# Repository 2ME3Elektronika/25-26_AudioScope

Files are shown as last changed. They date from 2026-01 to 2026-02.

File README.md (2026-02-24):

# Idea of the project
A professional DIY project for real-time audio frequency spectrum visualization (20Hz-20KHz) using Raspberry Pi 4, Adafruit RGB Matrix HAT, and 64x64 RGB LED Matrix.



# Characteristics
- Visualizes frequencies from **20Hz-20kHz**.
- **Multiple** available imputs (Jack, RCA, ...).
- **Microphone** to test that the visualizer works.
- **Oled I2C display** with multiple functions.
# What is a **RGB matrix 64x64**
The **GRB Matrix 64x64** is an LED matrix display that allows images, animations, and text to be shown in a colorful and dynamic way. Its main features include:

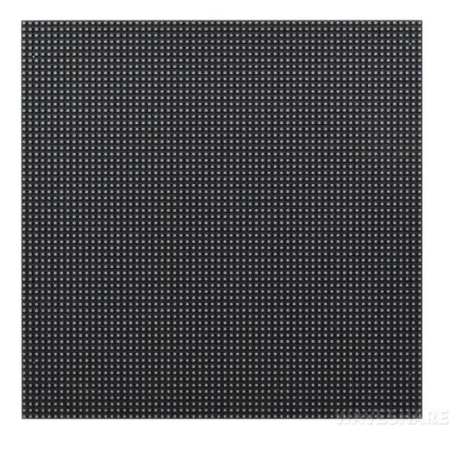
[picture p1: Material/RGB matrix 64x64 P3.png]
image alt

- **64x64 LED matrix:** Composed of 64 rows and 64 columns, totaling 4096 individual LEDs.
- **GRB color format:** Each LED is RGB (Red, Green, Blue), but the color data is sent in Green → Red → Blue order, ensuring colors display correctly.
- **Microcontroller control:** Can be driven with boards like Arduino or Raspberry Pi using specific matrix drivers such as Hub75.
- **High display capability:** Suitable for showing graphics, animations, and text in real time.
- **Standard protocol compatibility:** Allows efficient color data transfer and matrix synchronization.

In this project, the GRB Matrix 64x64 is responsible for displaying a **frequency** into a animated **FFT**, working together with the microcontroller that manages the system logic.

# Hardware 
Here’s a link to the guide for all the hardware you’ll need for this project

(https://github.com/2ME3Elektronika/25-26_AudioScope/blob/5edb63df820f065019aefbd5968ed1fb7cb71b74/HARDWARE.md)

# How To Use It?
1. Conect the power supply cable to a plug.
2. Click the power on **Button**.
3. Select the option you want to use with the **Rotary Encoder**.

Depending of the option you choose there are two routes.

## Microphone test mode
If you chose the **Microphone Test Mode**:

4. Talk to the microphone.
5. See if the display is showing the voice frequencies into FFT.

## Amplifier Test Mode
If you chose the **Amplifier Test Mode**:

4. Insert the output of the amplifier into of the inputs of the AudioScope.
5. See if the display is showing the frequencies into FFT.

# Preview Of The Project

Gemini_Generated_Image_q8y5mxq8y5mxq8y5
.
c96424af-a062-4ec9-849e-a771dd6d81b2aaaaa

## How the System Processes Audio
To turn raw sound into those dancing bars on your 64x64 matrix, the Raspberry Pi performs several complex operations in milliseconds.

### The Digital Processing Chain
1.  **Sampling:** The Pi captures the analog signal (Jack/RCA/Mic) via a USB Sound Card or I2S ADC at a standard rate (usually 44.1kHz).
2.  **FFT Algorithm:** The system applies a **Fast Fourier Transform**. This mathematical process takes the "messy" time-domain wave and breaks it into its constituent frequencies.
3.  **Mapping:** Since the matrix has 64 columns, the $20\text{Hz} - 20\text{kHz}$ range is divided into 64 discrete "bins":
    * **Lower bins (left):** Kick drums and bass guitar.
    * **Higher bins (right):** Cymbals and hi-hats.
4.  **Rendering:** The Adafruit RGB Matrix HAT translates these values into PWM (Pulse Width Modulation) signals to drive the HUB75 interface.

---

## Software Architecture
The system uses a high-performance stack to ensure real-time response without lag:

| Component | Function |
| :--- | :--- |
| **Python / C++** | Main logic & Rotary Encoder interrupt handling. |
| **ALSA / PortAudio** | Linux audio interface to "listen" to the input stream. |
| **rpi-rgb-led-matrix** | Low-level C++ driver for high-speed LED flickering. |
| **Luma.OLED** | Library for the I2C menu system and status display. |

---

## Expected Visual Modes
Customize your experience by switching between these visualization styles:

* **Classic Bar Spectrum:** Vertical bars with "peak drop" (a single pixel that stays at the top before falling).
* **Spectrogram:** A "waterfall" view where frequencies scroll downward over time.
* **Mirror Mode:** Bars grow from the horizontal center both upward and downward.
* **Pulse Mode:** The entire matrix pulses in color based on the intensity of the sub-bass.

---

## Final Tips for Success
> [!IMPORTANT]
> **Power Supply:** A 64x64 matrix can pull up to 4A. Use a **5V 10A** power supply to ensure stability for both the Pi and the LEDs.

* **Noise Floor:** Implement a software **noise gate** to keep the display clean when no music is playing.
* **Performance:** Use **Raspberry Pi OS Lite** to minimize background tasks and prevent "flickering" on the matrix.

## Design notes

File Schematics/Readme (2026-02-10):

You can download a Proteus file that lets you view the electrical circuit and create or order the PCB.

Each of the components are named in order to represent what they are inside of the pcb.

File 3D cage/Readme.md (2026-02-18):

# Building information

This section has been created to include the 3D part designs of the project. Throughout the development process, the project has evolved significantly over time, which has led to multiple changes and improvements in the designs. The files presented here correspond to the final versions of the parts.

Additionally, I have attached some images showing the initial design concepts to illustrate how the project has progressed from its early ideas to the final result.

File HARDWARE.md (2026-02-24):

#  Hardware Requirements

### Core Components
  1. **Raspberry Pi 4 Model B** (2GB or 4GB RAM recommended)

  2. **Adafruit RGB Matrix HAT + RTC for Raspberry Pi**
     - Provides clean 5V power to LED matrix and level-shifted outputs

  4. **64x64 RGB LED Matrix Panel - 3mm Pitch**
      - 3mm pitch recommended for better resolution
  
  5. **5V 4A (4000mA) Power Supply**
      - For powering the LED matrix
      - Minimum 4A for full brightness on 64x64 matrix

### Audio Input Hardware

### For Low-Level Signals (10mV-1V)
 **ADS1115 16-Bit ADC**
   - 4-channel, 16-bit resolution
   - I2C interface
   - Programmable gain amplifier (PGA)
   - Adafruit Product ID: 1085 or compatible

 **Input Protection Circuit Components:**
   - 1x Voltage divider resistors (10kΩ and 1kΩ)
   - 1x Capacitor 10µF (DC blocking)
   - 1x Op-amp (optional): TL072 or similar for signal conditioning
   - 2x Zener diodes 3.3V (input protection)
   - BNC or 3.5mm jack connector

### For High-Power Audio (40W Output)
#### USB Audio Interface
   - Any USB audio interface compatible with Raspberry Pi
   - Recommended: Behringer UCA202 or similar
   - Line-level input capability

** Voltage Divider/Attenuator Circuit:**
   - Resistors: 100kΩ and 10kΩ (10:1 attenuation)
   - Capacitor: 100µF (power supply decoupling)
   - Heat-shrink tubing or enclosure
   - Speaker wire connectors
     
#### Menu/Display Components
**Character LCD 20x4 with I2C backpack** OR **128x64 OLED Display**
   - For menu system and settings display
   - I2C interface preferred for easy connection
   - Options:
     - HD44780-compatible 20x4 LCD (recommended)
     - SSD1306 128x64 OLED display

## Power Considerations

### Power Budget
- Raspberry Pi 4: ~3W (600mA @ 5V)
- RGB Matrix HAT: ~0.5W (100mA @ 5V)
- 64x64 LED Matrix (full white): ~20W (4000mA @ 5V)
- 64x64 LED Matrix (typical usage): ~10W (2000mA @ 5V)
- LCD Display: ~0.5W (100mA @ 5V)
- USB Audio Interface: ~0.5W (100mA @ 5V)

**Total:** ~15W typical, ~25W maximum

## Power Supply Recommendations
- Use separate 5V 4A supply for LED matrix (via RGB Matrix HAT)
- Raspberry Pi can be powered from HAT's barrel jack
- Or use official Raspberry Pi 15W USB-C power supply
  
## Safety Notes
- Never exceed voltage ratings
- Use fuses on all power inputs
- Ensure proper grounding
- Keep high-power audio circuit isolated
- Use insulated connectors and enclosures

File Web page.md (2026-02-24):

---

## 🖥️ Web Interface
To interact with the project data and monitoring system, we have developed a dedicated web dashboard. You can access the live interface by clicking the banner below:

Web Preview (https://147810376.hs-sites-eu1.com/home)

*Click on the image to open the live dashboard and explore the AudioScope controls.*

### Key Web Features:
* **Real-time Monitoring:** Visual feedback of the audio signals processed by the Raspberry Pi.
* **Remote Control:** Adjust parameters and visualization modes directly from your browser.
* **Device Status:** Check the connectivity and system health of your AudioScope unit.

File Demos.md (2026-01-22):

To be able of running some demos we decided to use the next website
(https://learn.adafruit.com/adafruit-rgb-matrix-plus-real-time-clock-hat-for-raspberry-pi/install-manually)

To see if our 64x64 rgb led matrix the next library can be used to see some demos.
-     git clone https://github.com/hzeller/rpi-rgb-led-matrix.git  cd rpi-rgb-led-matrix  make

Once you´re inside of the examples-api-use subdirectory the next code can be used to prove some examples. By changing the number at the end of the code (0-9) different samples can be put on the 64x64 matrix
-     sudo ./demo -D 0

If you encounter an image problem when running the demo, you should open the demo.py file located in the examples-api-use subdirectory and find the two lines that say rows and columns and change them from 32 to 64.

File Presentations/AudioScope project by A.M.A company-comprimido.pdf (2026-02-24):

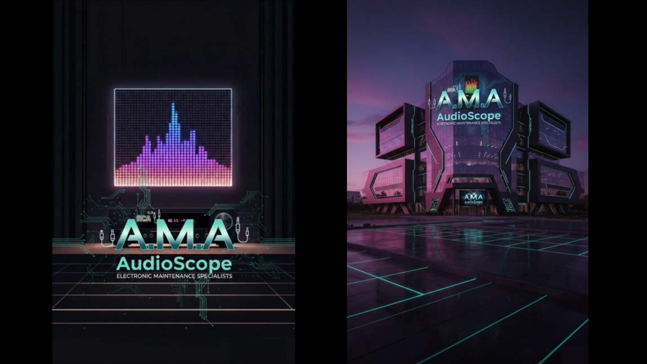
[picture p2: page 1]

# WHO ARE WE?

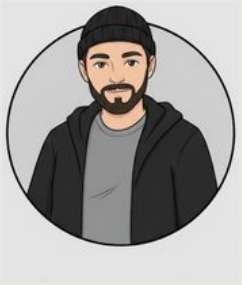
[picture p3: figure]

## Programer and CEO of the company

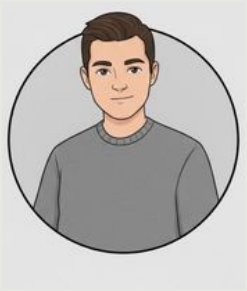
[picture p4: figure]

## 3D designer, assembler and marketing manager

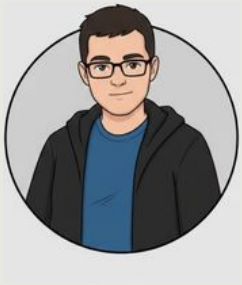
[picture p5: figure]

## PCB designer/soldier and troubleshooting

# WHAT IS OUR PURPOSE?

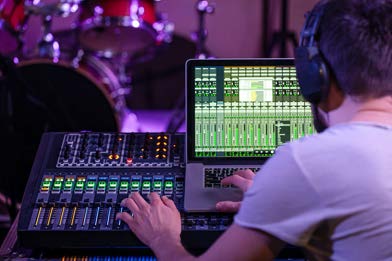
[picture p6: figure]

- Audio System
Optimization

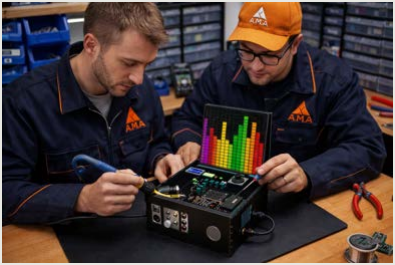
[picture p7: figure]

- Preventive Maintenance
- Hardware Restoration
- Component-level Repair

# WHAT IS AUDIOSCOPE?

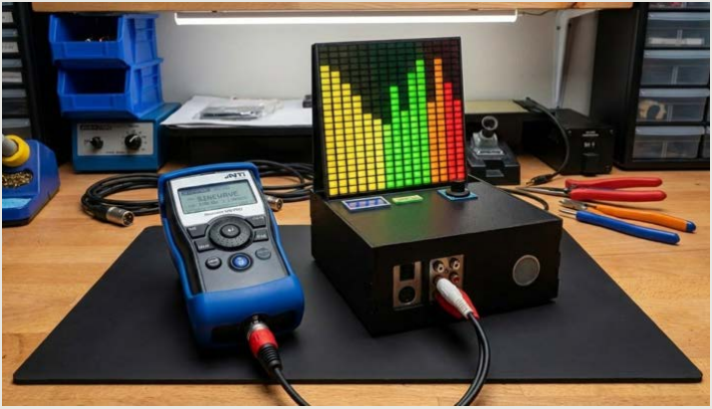
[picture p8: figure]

Video (https://drive.google.com/drive/folders/1TKRi724KOL6Fbhr36j2Ks8M4P-jSvRjH?usp=sharing)

# WHAT IS AUDIOSCOPE PRODUCT FOCUSED ON?

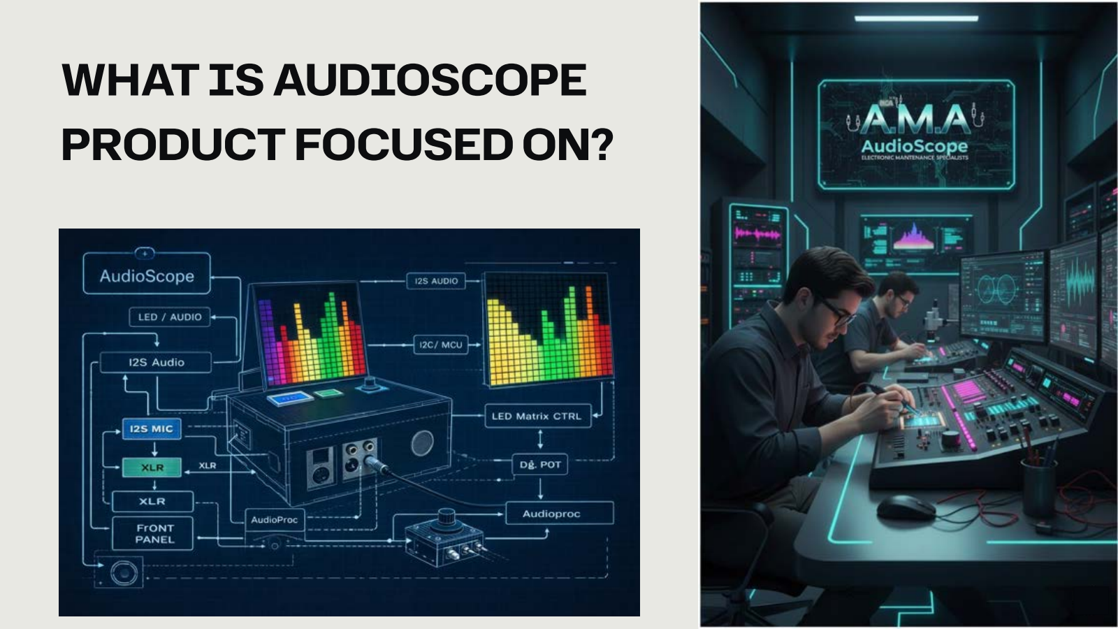
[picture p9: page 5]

# THE ROLE OF AI IN AUDIOSCOPE

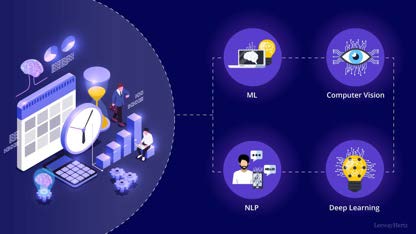
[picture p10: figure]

- Expert guidance in choosing the most compatible and high-performance electronic elements for the project.

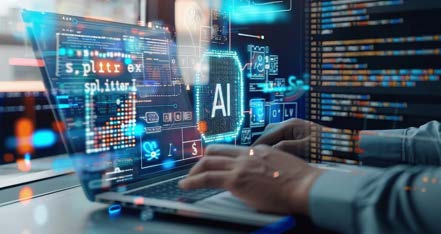
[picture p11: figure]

- Using AI suggestions to optimize code logic and ensure the fastest possible frequency processing.

# FUTURE IMPROVEMENTS TO AUDIOSCOPE

- Connectivity:
Integration of Bluetooth
and Wi-Fi streaming for
a wireless experience.
- Smart Features: AI-driven genre recognition to
automatically adapt visual styles.

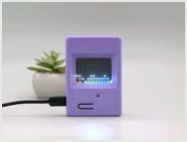
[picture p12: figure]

- Audio Quality: Upgrading to high-end I2S DACs for
professional-grade signal
processing.
- Portability: Implementation of internal battery systems and compact housing.

# DRIVING TOMORROW'S SUCCESS, TODAY

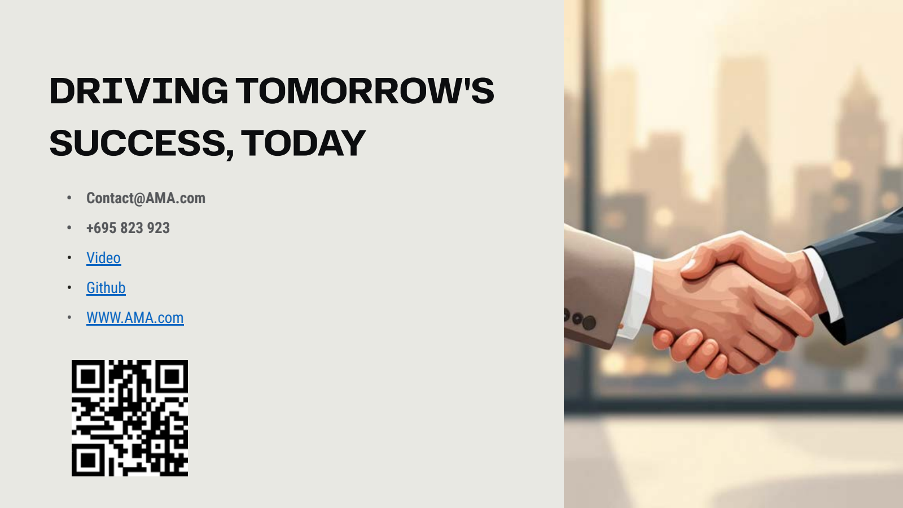
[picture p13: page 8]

- Contact@AMA.com
- +695 823 923
- Video (https://drive.google.com/drive/folders/1TKRi724KOL6Fbhr36j2Ks8M4P-jSvRjH?usp=sharing)
- Github (https://github.com/2ME3Elektronika/25-26_AudioScope)
- WWW.AMA.com (https://147810376.hs-sites-eu1.com/home)

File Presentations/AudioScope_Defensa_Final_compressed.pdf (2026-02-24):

# AUDIOSCOPE

## Sistema Embebido de Visualización Espectral en Tiempo Real

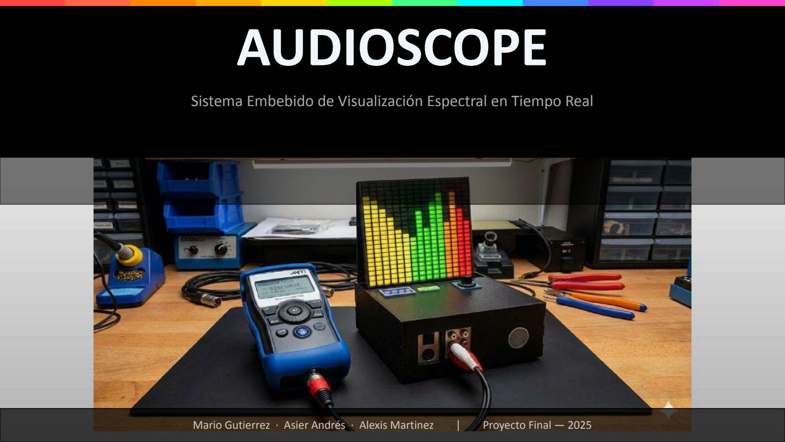
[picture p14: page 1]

Mario Gutierrez · Asier Andrés · Alexis Martinez | | | Proyecto Final — 2025

# AUDIOSCOPE — VISIÓN GENERAL

### Analizador espectral embebido con visualización RGB 64×64 y control I²C

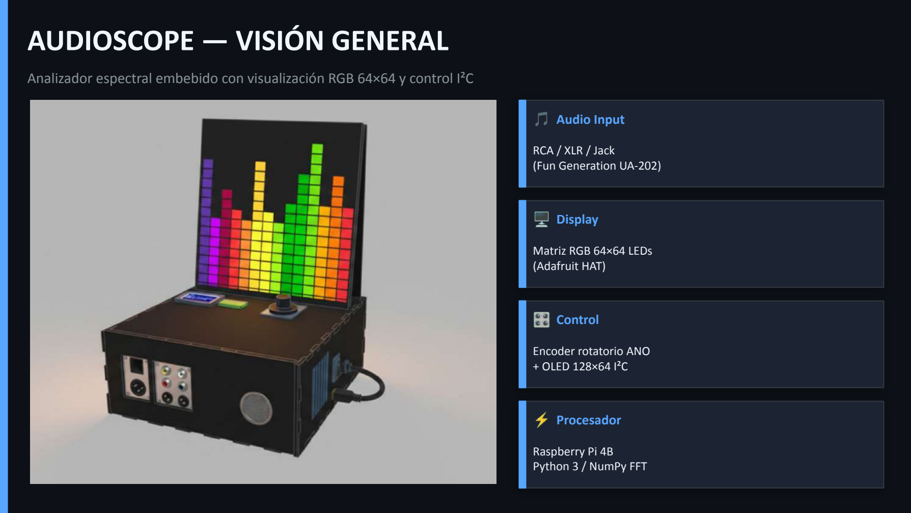
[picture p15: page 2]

🎵 Audio Input

RCA / XLR / Jack
(Fun Generation UA-202)

🖥 Display

Matriz RGB 64×64 LEDs
(Adafruit HAT)

🎛 Control

Encoder rotatorio ANO
+ OLED 128×64 I²C

⚡ Procesador

Raspberry Pi 4B
Python 3 / NumPy FFT

# 01 — ARQUITECTURA HARDWARE

### Diagrama de conexiones y flujo de señal completo

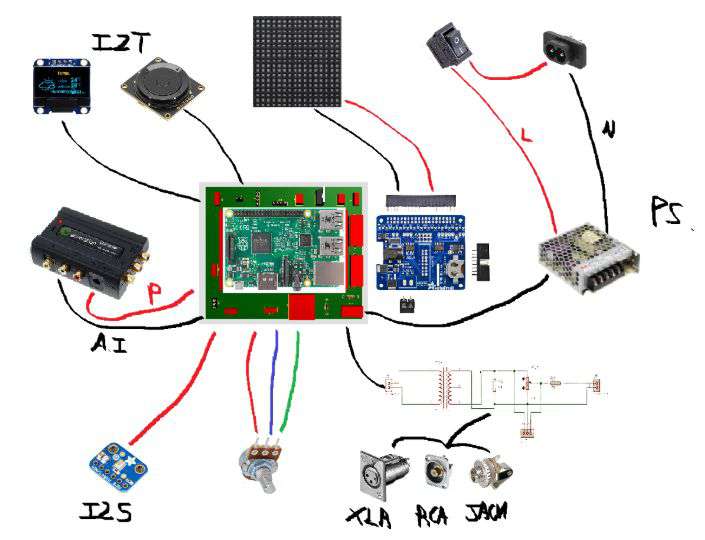
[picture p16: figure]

# 02 — PINOUT RASPBERRY PI & BUS I²C

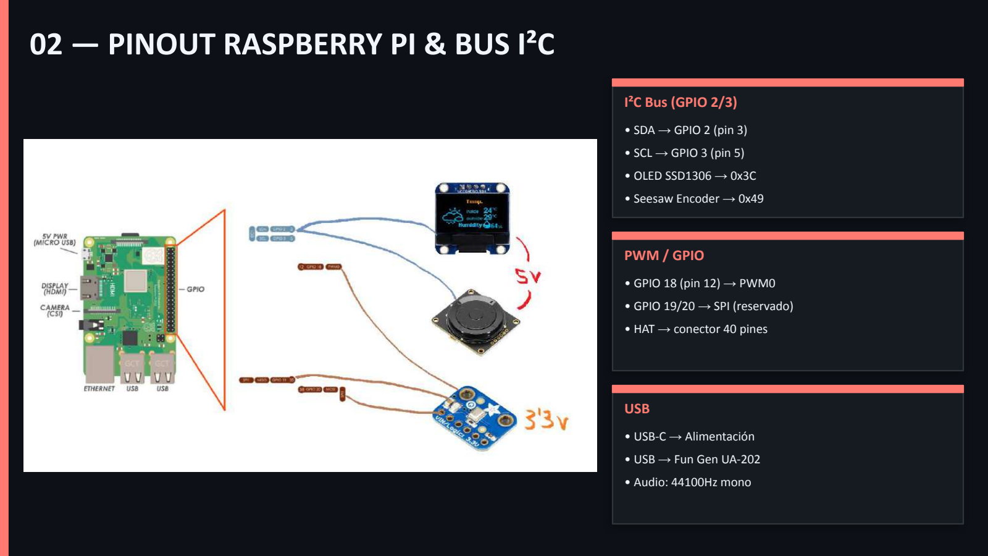
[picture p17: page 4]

I²C Bus (GPIO 2/3)

- SDA → GPIO 2 (pin 3)
- SCL → GPIO 3 (pin 5)
- OLED SSD1306 → 0x3C
- Seesaw Encoder → 0x49

PWM / GPIO

- GPIO 18 (pin 12) → PWM0
- GPIO 19/20 → SPI (reservado)
- HAT → conector 40 pines

USB

- USB-C → Alimentación
- USB → Fun Gen UA-202
- Audio: 44100Hz mono

# 03 — ARQUITECTURA SOFTWARE

### 3 módulos Python · threading.Thread · Callback de audio asíncrono

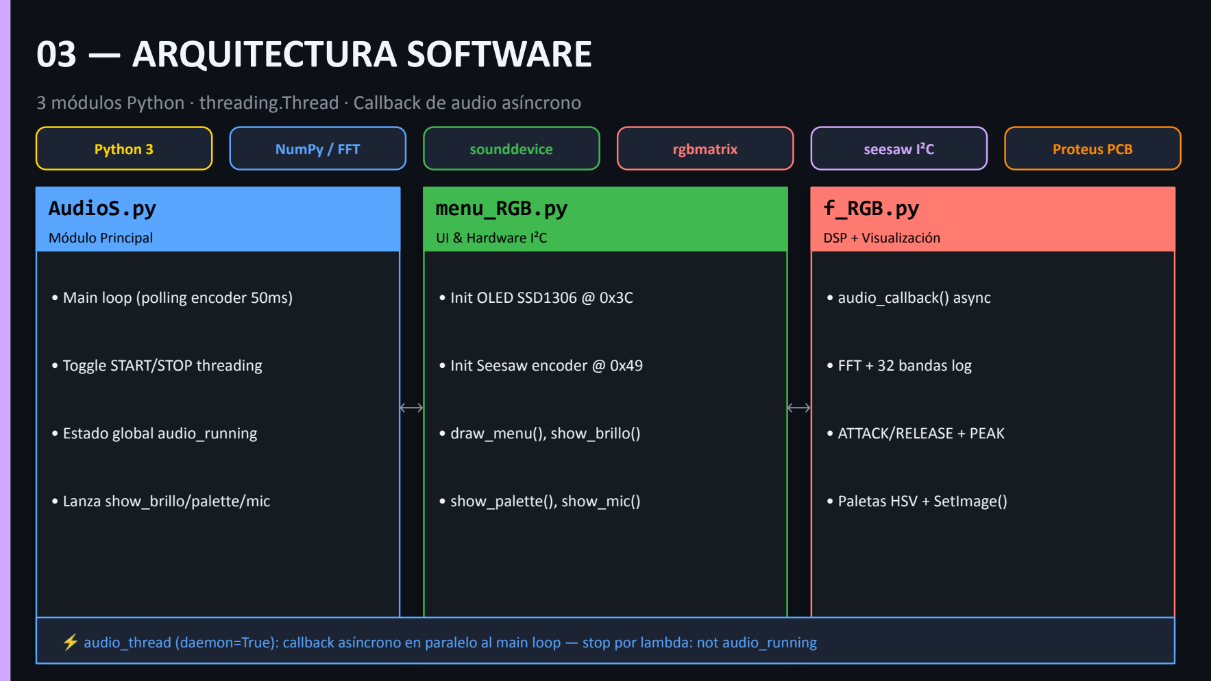
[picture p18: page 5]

Python 3 | NumPy / FFT | sounddevice | rgbmatrix | seesaw I²C | Proteus PCB

## AudioS.py

Módulo Principal

- Main loop (polling encoder 50ms)
- Toggle START/STOP threading
- Estado global audio_running
- Lanza show_brillo/palette/mic

## menu_RGB.py

UI & Hardware I²C

- Init OLED SSD1306 @ 0x3C
- Init Seesaw encoder @ 0x49
- draw_menu(), show_brillo()
- show_palette(), show_mic()

## f_RGB.py

DSP + Visualización

- audio_callback() async
- FFT + 32 bandas log
- ATTACK/RELEASE + PEAK
- Paletas HSV + SetImage()
⟷ | ⟷

audio_thread (daemon=True): callback asíncrono en paralelo al main loop — stop por lambda: not audio_running

# 04 — PIPELINE DE AUDIO & DSP

### Captura USB → Windowing → FFT → 32 bandas logarítmicas → Normalización

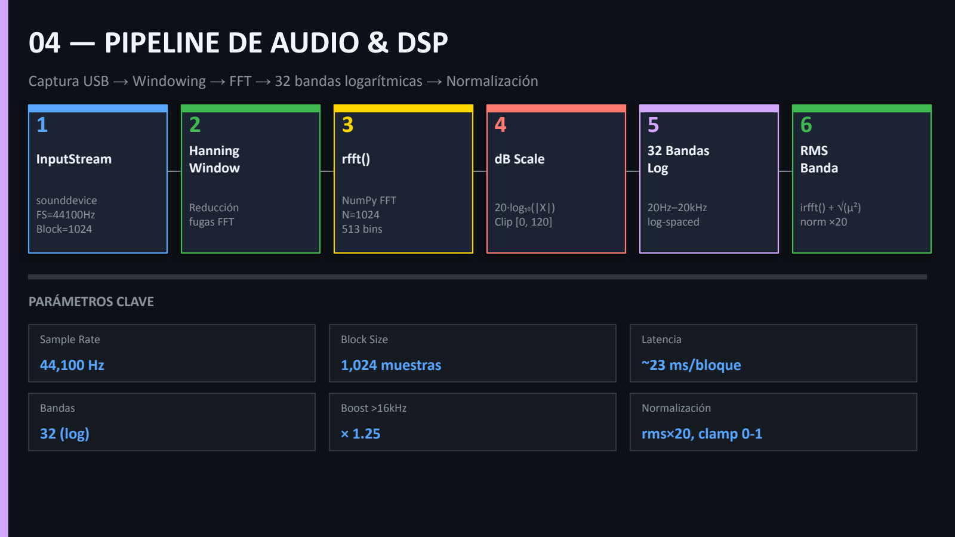
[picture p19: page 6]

1

InputStream

sounddevice
FS=44100Hz
Block=1024

→

2

Hanning
Window

Reducción
fugas FFT

→

3

rfft()

NumPy FFT
N=1024
513 bins

→

4

dB Scale

20·log₁₀(|X|)
Clip [0, 120]

→

5

### 32 Bandas

Log

20Hz–20kHz
log-spaced

→

6

RMS
Banda

irfft() + √(μ²)
norm ×20

PARÁMETROS CLAVE

Sample Rate
44,100 Hz

Block Size

### 1,024 muestras

Latencia

### ~23 ms/bloque

Bandas

### 32 (log)

Boost >16kHz
× 1.25

Normalización

### rms×20, clamp 0-1

# 05 — MOTOR DE VISUALIZACIÓN RGB

### Suavizado dinámico, barras de pico y 5 paletas HSV con degradado 3D

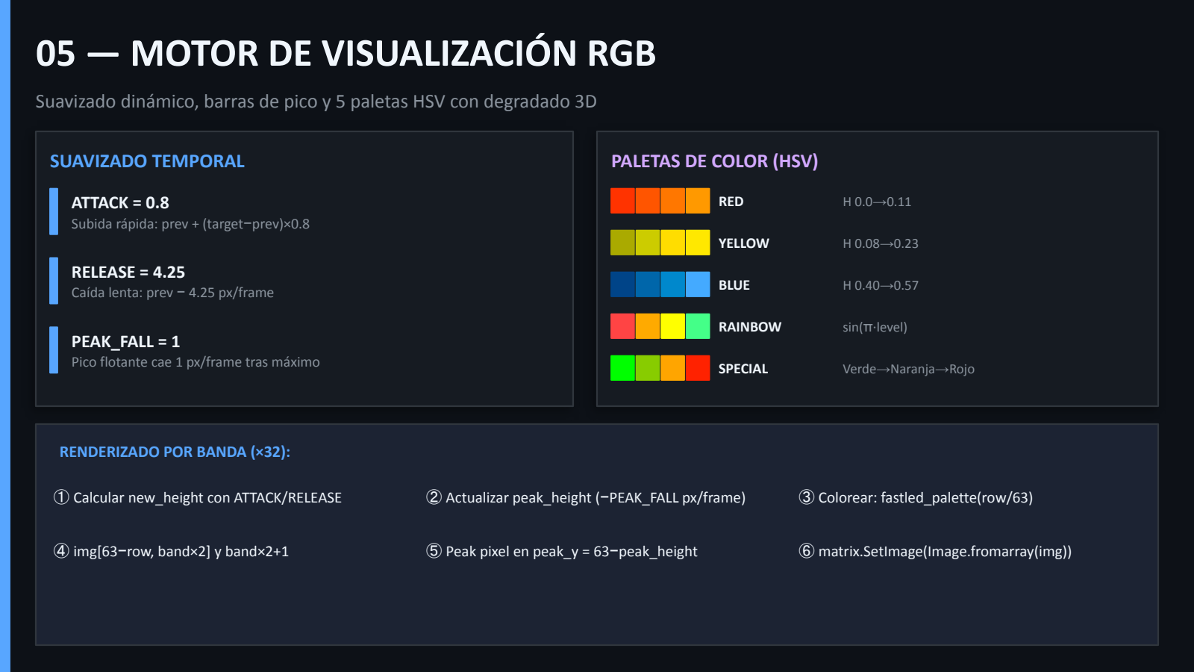
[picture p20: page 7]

### SUAVIZADO TEMPORAL

ATTACK = 0.8
Subida rápida: prev + (target−prev)×0.8

RELEASE = 4.25
Caída lenta: prev − 4.25 px/frame

PEAK_FALL = 1
Pico flotante cae 1 px/frame tras máximo

### PALETAS DE COLOR (HSV)

RED | H 0.0→0.11
YELLOW | H 0.08→0.23
BLUE | H 0.40→0.57
RAINBOW | sin(π·level)
SPECIAL | Verde→Naranja→Rojo

RENDERIZADO POR BANDA (×32):

① Calcular new_height con ATTACK/RELEASE | ② Actualizar peak_height (−PEAK_FALL px/frame) | ③ Colorear: fastled_palette(row/63)
④ img[63−row, band×2] y band×2+1 | ⑤ Peak pixel en peak_y = 63−peak_height | ⑥ matrix.SetImage(Image.fromarray(img))

# 06 — INTERFAZ DE USUARIO

### OLED 128×64 (0x3C) + Encoder ANO Seesaw I²C (0x49) + 4 botones

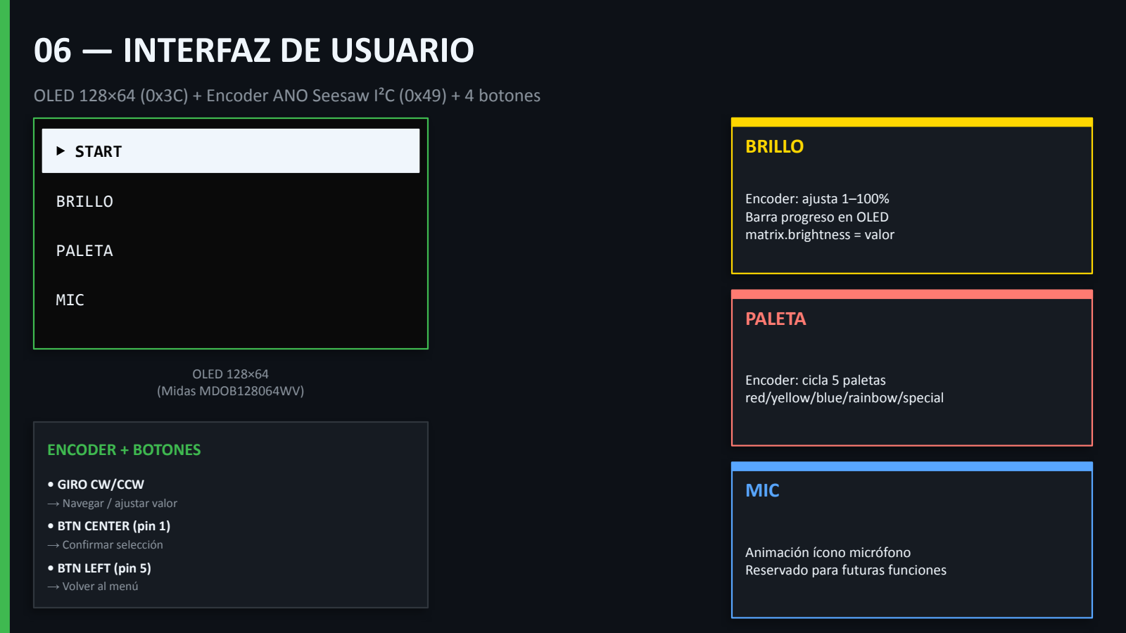
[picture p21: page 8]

- START

BRILLO

PALETA

MIC

OLED 128×64
(Midas MDOB128064WV)

ENCODER + BOTONES

- GIRO CW/CCW
→ Navegar / ajustar valor
- BTN CENTER (pin 1)
→ Confirmar selección
- BTN LEFT (pin 5)
→ Volver al menú

## BRILLO

Encoder: ajusta 1–100%
Barra progreso en OLED
matrix.brightness = valor

## PALETA

Encoder: cicla 5 paletas
red/yellow/blue/rainbow/special

## MIC

Animación ícono micrófono
Reservado para futuras funciones

# 07 — DISEÑO MECÁNICO & CARCASA

### Piezas diseñadas en Inkscape + MakerCase — Impresión 3D

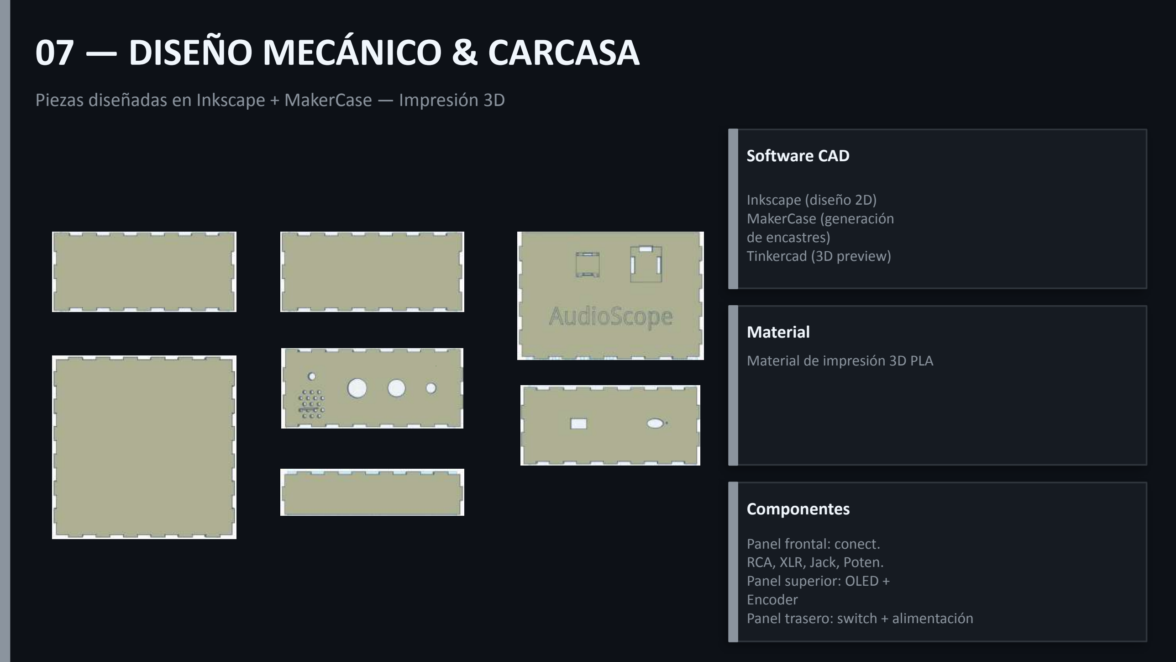
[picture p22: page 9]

Software CAD

Inkscape (diseño 2D)
MakerCase (generación
de encastres)
Tinkercad (3D preview)

Material

Material de impresión 3D PLA

Componentes

Panel frontal: conect.
RCA, XLR, Jack, Poten.
Panel superior: OLED +
Encoder
Panel trasero: switch + alimentación

# 08 — DISEÑO ELECTRÓNICO (Proteus + PCB)

### Esquemático en Proteus · PCB 3D con fuente de alimentación integrada

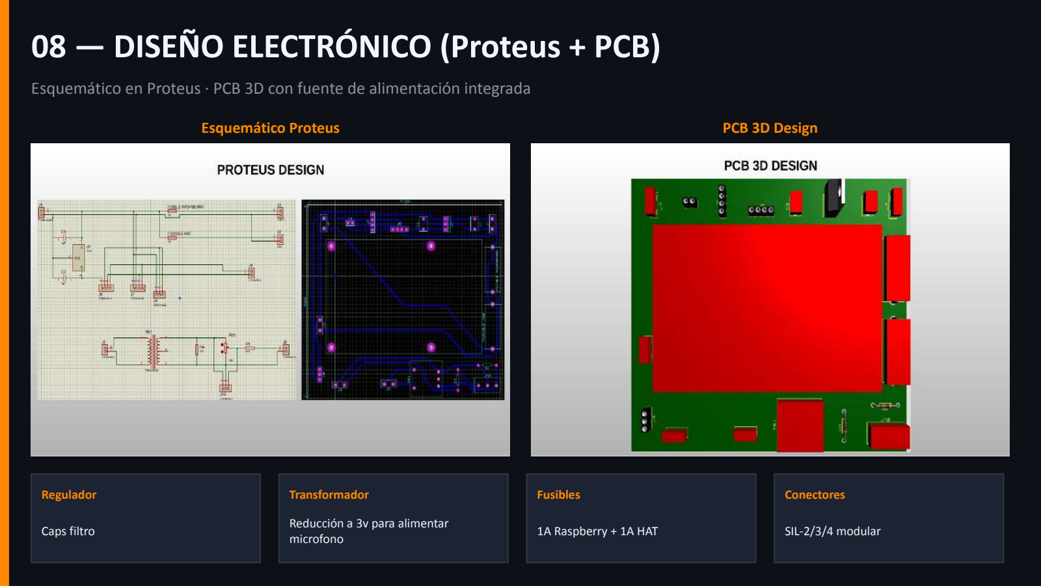
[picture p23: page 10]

Esquemático Proteus | PCB 3D Design

Regulador

Caps filtro

Transformador

Reducción a 3v para alimentar microfono

Fusibles

1A Raspberry + 1A HAT

Conectores

SIL-2/3/4 modular

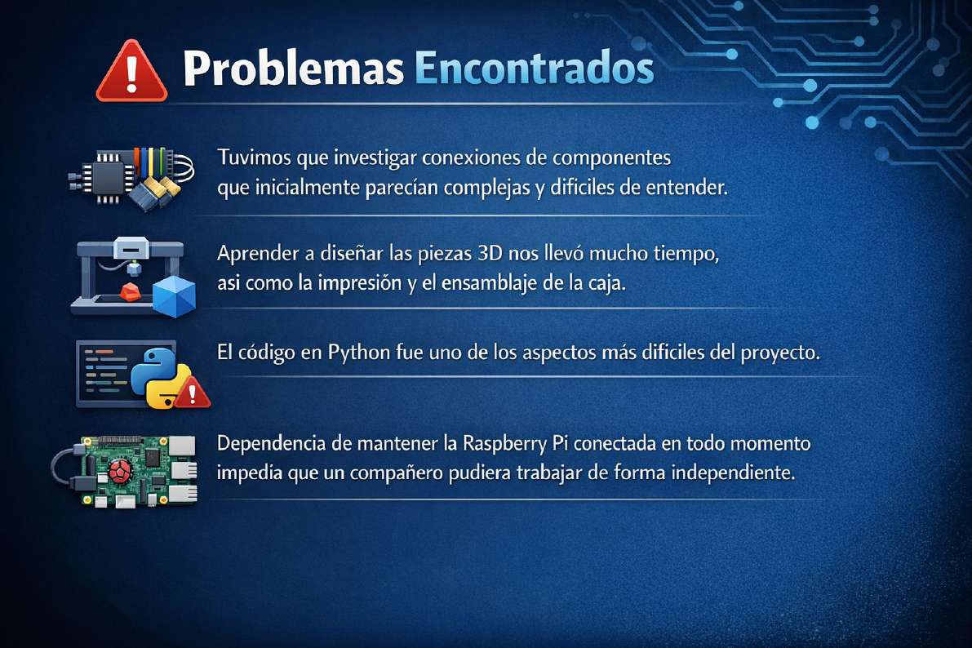
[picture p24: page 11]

# 🔧 FUTURAS MEJORAS

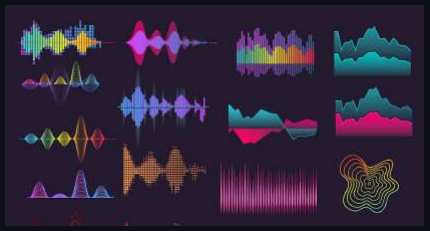
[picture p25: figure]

Más estilos visuales

Osciloscopio(sinusoidal), circular, etc…


Pantalla RGB mayor

Configurar una segunda matriz P3 64×64


Altavoces integrados

Escuchar el audio en el dispositivo a la vez que se pueda visualizar el display

# A.M.A

# AudioScope


Electronic Maintenance Specialists

- Video demo (https://drive.google.com/drive/folders/1TKRi724KOL6Fbhr36j2Ks8M4P-jSvRjH?usp=sharing)
⌥ | GitHub — código fuente (https://github.com/2ME3Elektronika/25-26_AudioScope)
| Webpage del proyecto (https://147810376.hs-sites-eu1.com/home)
| Instagram (https://www.instagram.com/audioscope2026/)
Escanea para
acceder al proyecto

Mario Gutierrez · Asier Andrés · Alexis Martinez

## TikTok (https://www.tiktok.com/@audioscope2026?is_from_webapp=1&sender_device=pc)

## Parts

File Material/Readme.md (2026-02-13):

# Oled I2C Display
We are using an I2C display to be able to visualize the different options available when using the AudioScope.

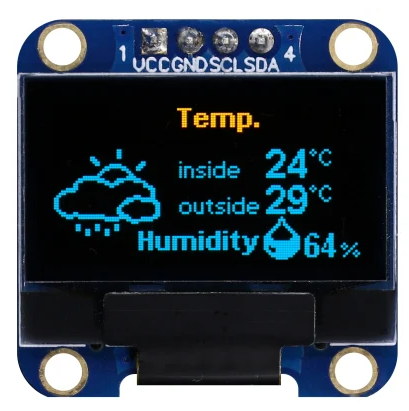
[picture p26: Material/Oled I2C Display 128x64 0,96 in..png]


## Connections
- **VCC:** It is supllied with 5v by the 5v 10A power supply.
- **GND:** It is conected to the GND of the power supply.
- **SDA (Serial Data):** it is connected to the pin SDA of the adafruit hat.
- **SCL (Serial Clock):** it is connected to the pin SCL of the adafruit hat.

# Oled I2C Rotatory Encoder
The rotatory encoder is used to select between the different options that the oled i2c display gives us.

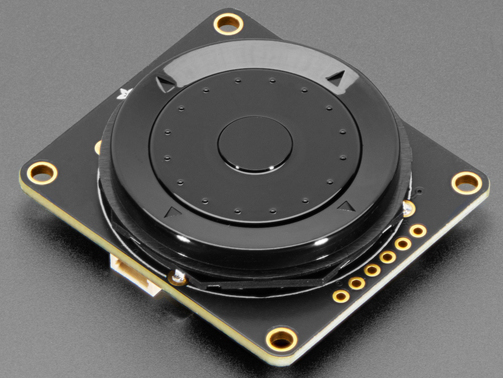
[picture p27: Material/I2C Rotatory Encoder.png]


## Connections
- **VCC:** It is supplied with 5v by the 5v 10A power supply.
- **GND:** It is conected to the GND of the power supply.
- **SDA (Serial Data):** it is connected to the pin SDA of the adafruit hat.
- **SCL (Serial Clock):** it is connected to the pin SCL of the adafruit hat.

# I2S Microphone
This microphone is used to be able to test that the AudioScope is working properly.

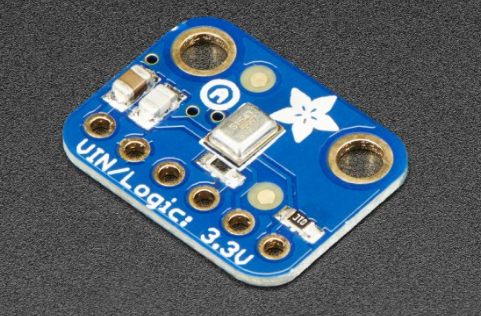
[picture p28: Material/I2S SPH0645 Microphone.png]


## Connections
- **VCC:** It is supplied with 3,3v that come out of the regulator.
- **GND:** It is conected to the GND of the power supply.
- **BCLK:** It is conected to the GPIO 18 of the adafruit hat
- **LRCL/WS:** It is conected to the GPIO 19 of the adafruit hat
- **DOUT/SD:** It is conected to the GPIO 20 of the adafruit hat
- **Optional L/R (Channel selection):** In order to have a secundary sound channel it is conected to the GND of the power suplly.

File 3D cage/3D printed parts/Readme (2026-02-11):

The following 3D models are specifically designed to be printed with a 3D printer. Each component has been optimized for additive manufacturing, considering printability, layer adhesion, and support requirements.

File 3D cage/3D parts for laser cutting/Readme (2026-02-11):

The following 3D models are specifically designed to be fabricated using laser cutting, not 3D printing. Although the components are presented in 3D format for easier visualization and assembly, each part is intended to be cut from flat materials (such as MDF, acrylic, or plywood) and then assembled.

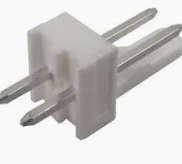
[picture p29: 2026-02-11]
Schematics/Material for PCB/Male 2 pin conector.png

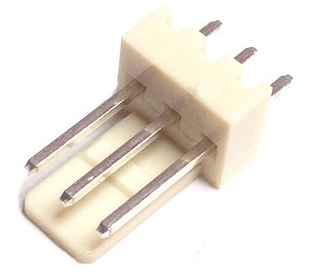
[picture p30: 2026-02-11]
Schematics/Material for PCB/Male 3 pin conector.png

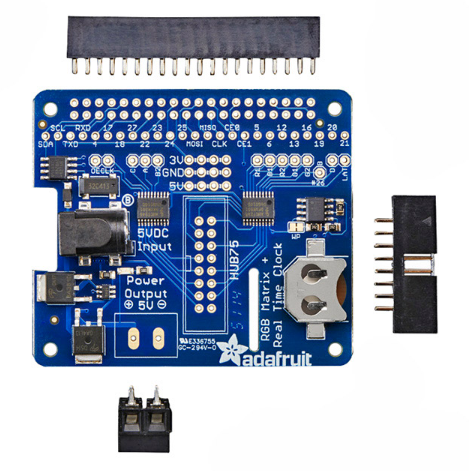
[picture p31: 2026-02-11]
Material/Adafruit RGB matrix hat.png

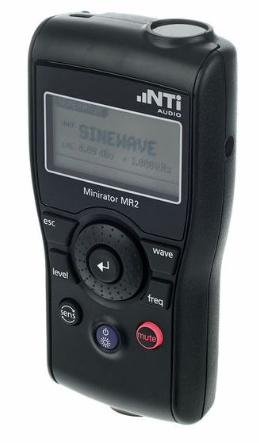
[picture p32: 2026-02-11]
Material/NTI Audio MR-2 Minirator.png

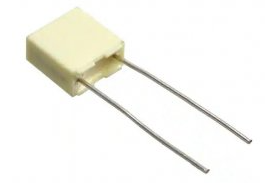
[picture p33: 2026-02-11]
Schematics/Material for PCB/1uf 63v capacitor.png

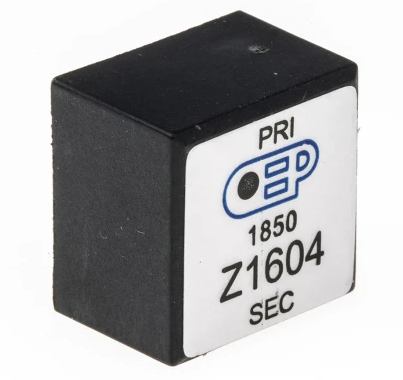
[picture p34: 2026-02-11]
Schematics/Material for PCB/Z1604 Transformer.png

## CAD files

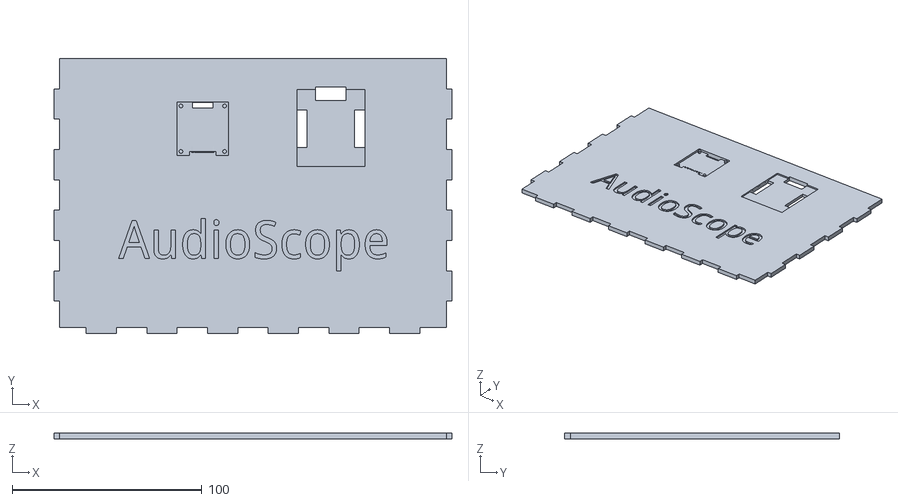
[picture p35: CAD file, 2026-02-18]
3D cage/3D printed parts/Pieza superior control AudioScope.stl
210.0 x 145.0 x 3.00

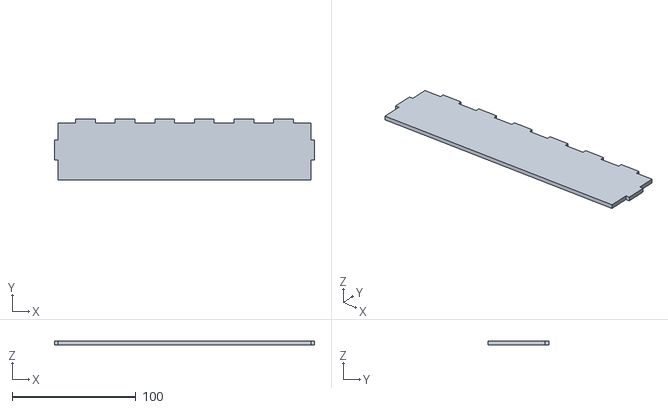
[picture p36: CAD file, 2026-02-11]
3D cage/3D printed parts/Pieza superior corta AudioScope.stl
210.0 x 49.0 x 3.00

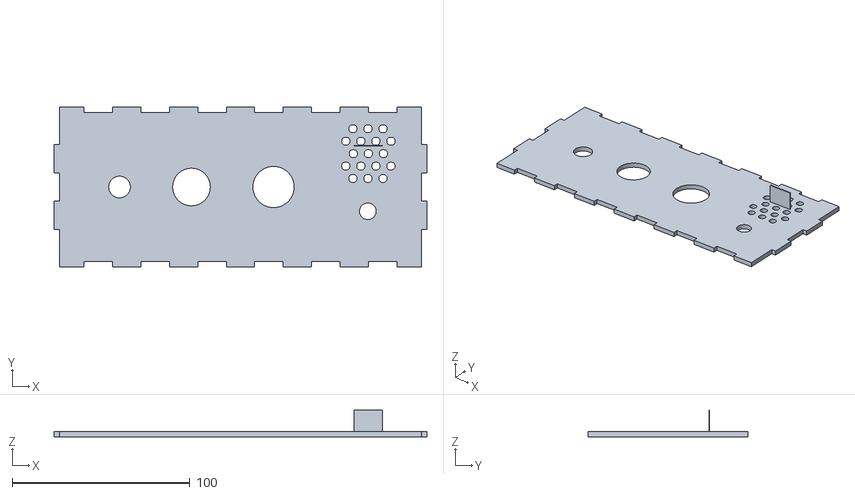
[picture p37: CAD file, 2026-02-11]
3D cage/3D printed parts/Pieza frontal AudioScope.stl
210.0 x 90.0 x 15.0

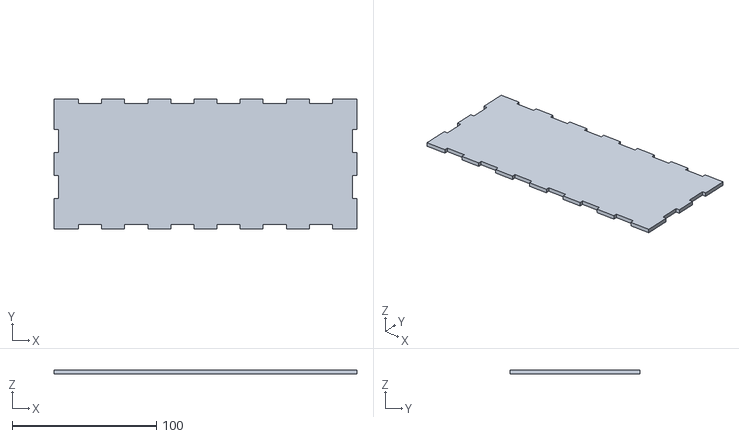
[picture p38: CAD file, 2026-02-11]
3D cage/3D printed parts/Pieza lateral Izquierda AudioScope.stl
210.0 x 90.0 x 3.00

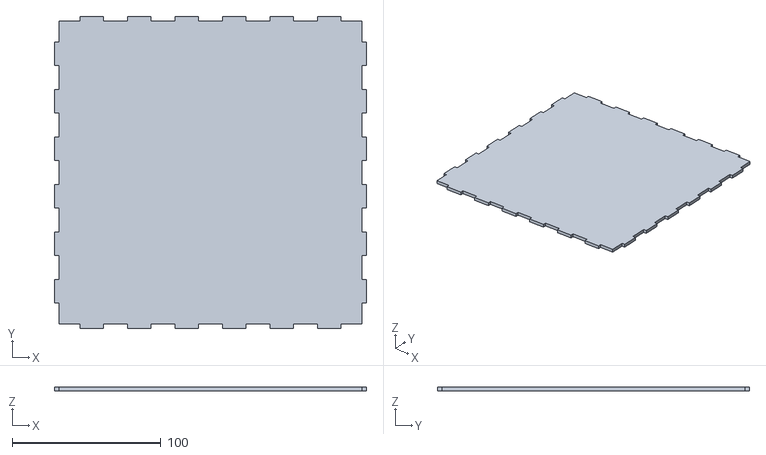
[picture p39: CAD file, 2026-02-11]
3D cage/3D printed parts/Pieza Inferior AudioScope.stl
210.0 x 210.0 x 3.00

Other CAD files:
3D cage/3D printed parts/Pieza lateral Derecha AudioScope.stl
3D cage/3D printed parts/Pieza trasera AudioScope.stl

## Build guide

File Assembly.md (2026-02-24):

# STEPS TO ASSEMBLE THE AUDIOSCOPE

## PRE-ASSEMBLY & PREPARATION
Before starting the physical construction, ensure you have completed these essential preparatory steps to ensure the "Brain" of the project is ready.

### 1. Software & Firmware Setup
Since the project is based on a Raspberry Pi, it is highly recommended to flash the OS and install the necessary drivers before mounting it inside the cage:
* **Flash the OS:** Install the required OS (Raspbian/Lite) onto your SD card.
* **Enable Interfaces:** Enable **I2C** and **I2S** interfaces via `raspi-config`.
* **Install Drivers:** Install the specific drivers for the **LED Matrix** and the **OLED display**.
* **Pro-tip:** Test all components on a breadboard before final soldering to ensure everything works correctly.

### 2. Component Verification
Check that you have all the components shown in the schematic:
* **Processing:** Raspberry Pi + GPIO Expansion Shield.
* **Displays:** LED Matrix (Main Visualizer) and I2C OLED Screen.
* **Audio Input:** Audio Interface (AI) and I2S Microphone/Module.
* **Controls:** Potentiometers and Navigation switches.
* **Power:** Power Supply (PS), AC Socket, and Power Switch.
* **Connectors:** XLR, RCA, and Jack 6.35mm terminals.

### 3. Tools Required
Prepare the following tools for the assembly:
* **Soldering Station:** For the wiring between the Raspberry Pi, sensors, and connectors.
* **Acetone & Brush:** For chemically welding the 3D printed parts (ABS/ASA).
* **Heat Shrink Tubing:** To insulate the connections, especially the AC power lines (L/N).
* **Precision Screwdriver Set:** To secure the Raspberry Pi and the Power Supply to the internal mounts.

### 4. Safety Warning
* **High Voltage:** The assembly involves wiring a Power Supply (PS) directly to an AC Socket. **Ensure the device is unplugged** during the entire wiring process.
* **Ventilation:** Use acetone in a well-ventilated area to avoid inhaling fumes during the cage assembly.

---

## 3D CAGE
[3D Printed Parts Directory](https://github.com/2ME3Elektronika/25-26_AudioScope/tree/19ac5f9debe1980ef2535abc0a953aee821c8050/3D%20cage/3D%20printed%20parts)

Through the previously provided link, the necessary parts to assemble the box that will contain all the project components are available.

To join the required pieces, acetone was used as the bonding agent.

---

## COMPONENT ASSEMBLY 
Once the cage is complete, the next step is to assemble all the components in the link below.

[Material List](https://github.com/2ME3Elektronika/25-26_AudioScope/tree/4716233cc459483782bc5c3bb550349c5cebfe78/Material)

To facilitate the examination of material connections, the following schematic diagram has been developed:

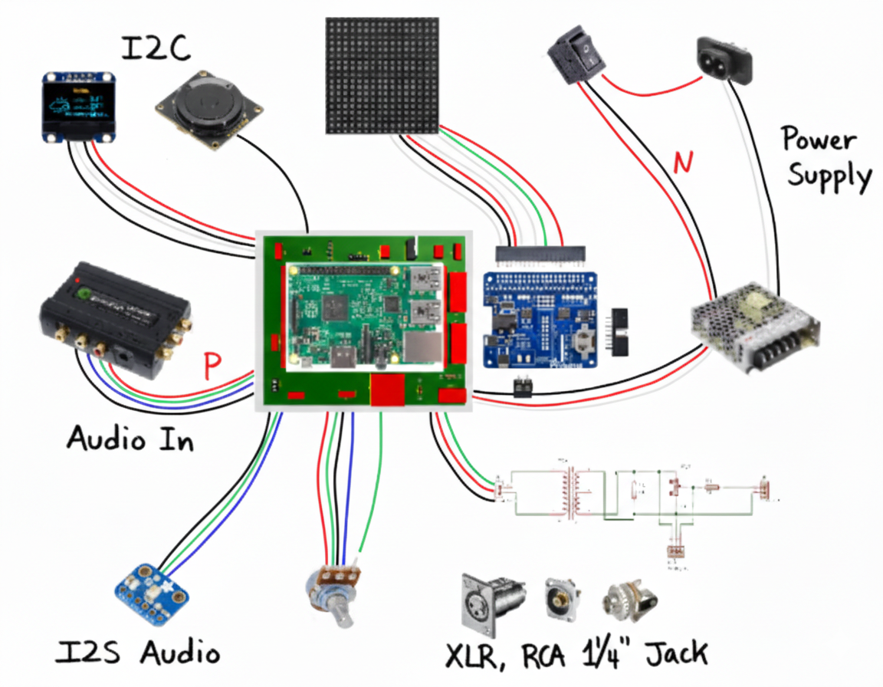
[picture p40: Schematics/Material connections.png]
image alt


To create the PCB that will enable the connection of all components, the following schematic has been developed:

[AudioScope PCB Project](https://github.com/2ME3Elektronika/25-26_AudioScope/blob/c6339670a8648a26b4ef2825f532ce45a1cc3c00/Schematics/AudioScope%20PCB.pdsprj)

To see the needed materials, the following directory has been developed:

[Full Materials Directory](https://github.com/2ME3Elektronika/25-26_AudioScope/tree/c6339670a8648a26b4ef2825f532ce45a1cc3c00/Material)

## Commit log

2026-01-14 Material to creater a Audio visualizer
2026-01-21 Update hardware requirements for audio and display
    Added components for high-power audio and display options.
2026-02-11 Update Readme to specify laser cutting use
    Clarified the purpose of the 3D models for laser cutting.
2026-02-11 Update Readme with details on 3D printed parts
    Added a description for 3D printed parts and their optimization.
2026-02-11 Create sample
2026-02-12 Add README for Oled I2C Display
2026-02-13 Fix spelling and voltage details in Readme.md
    Corrected spelling errors in the connections section and updated voltage information for components.
2026-02-24 Improve assembly section with additional resources
    Updated assembly instructions with links to components and schematic.
2026-02-24 Remove local image path from Assembly.md
    Removed local file path to an image from Assembly.md.
2026-02-24 Revise Assembly.md with schematic and material links
    Updated the Assembly.md to improve clarity and provide additional schematic diagrams and links for material connections and PCB creation.
2026-02-24 Document pre-assembly steps for Audioscope
    Added detailed pre-assembly steps, including software setup, component verification, required tools, and safety warnings for assembling the Audioscope.
